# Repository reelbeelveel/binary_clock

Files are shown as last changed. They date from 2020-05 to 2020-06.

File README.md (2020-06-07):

# project objective
The main objective of this project was to create a functioning digital clock using "basic" TTL chips (no Arduino, no RTC, etc.) which displays the current time in Binary using 21 Red/Green Light modules (that's 4 bits for milliseconds, 6 bits for seconds, 6 bits for minutes, 4 bits for the hour, and one bit for AM/PM).
# clock datapath revision 1
My first revision of the clock's main datapath was a BEAST. At this time, I was still pretty committed to building the system using low level components only, so this circuit board was monstrous.



In the second revision, (coming soon) I plan on replacing the adder/and/register structure (pictured below for the millisecond system) with a simple decade counter (7493). In my rough sketches, this has reduced the number of ICs from 26 to ~16 or so.

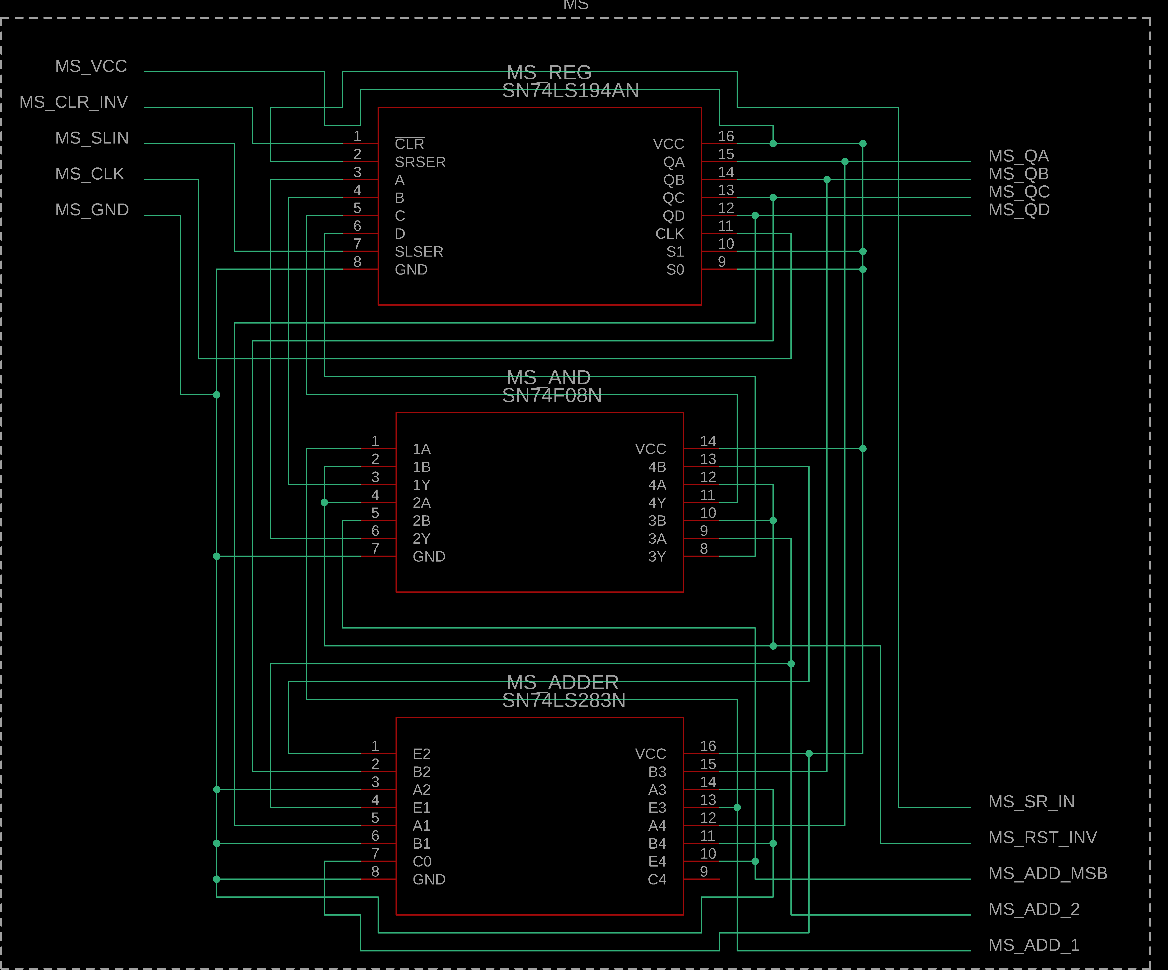
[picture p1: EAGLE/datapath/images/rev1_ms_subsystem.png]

#

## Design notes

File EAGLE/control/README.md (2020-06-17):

# Clock Control

## EAGLE Project, Revision 1*
## Quartus files currently unavailable for this Project.

---

## Schematics

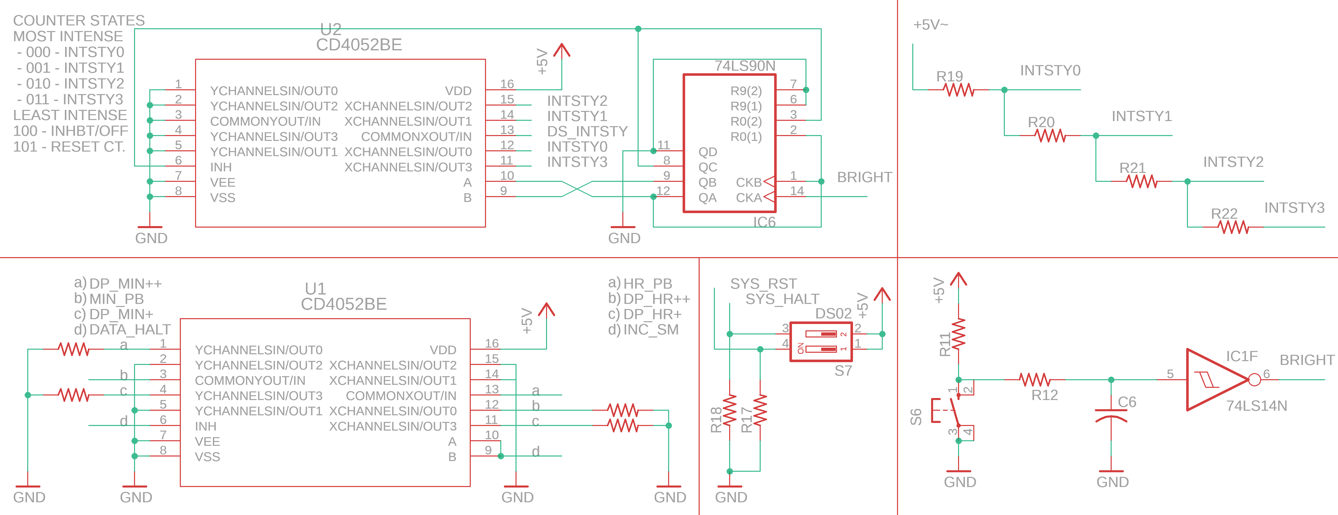
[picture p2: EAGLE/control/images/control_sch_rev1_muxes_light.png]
Control Schematic 1


---

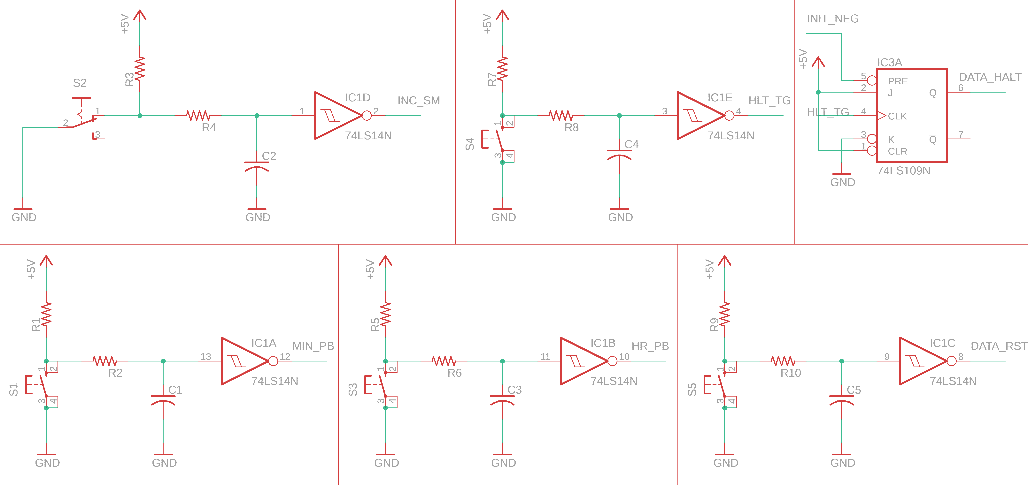
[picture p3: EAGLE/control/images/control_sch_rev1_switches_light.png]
Control Schematic 2


---

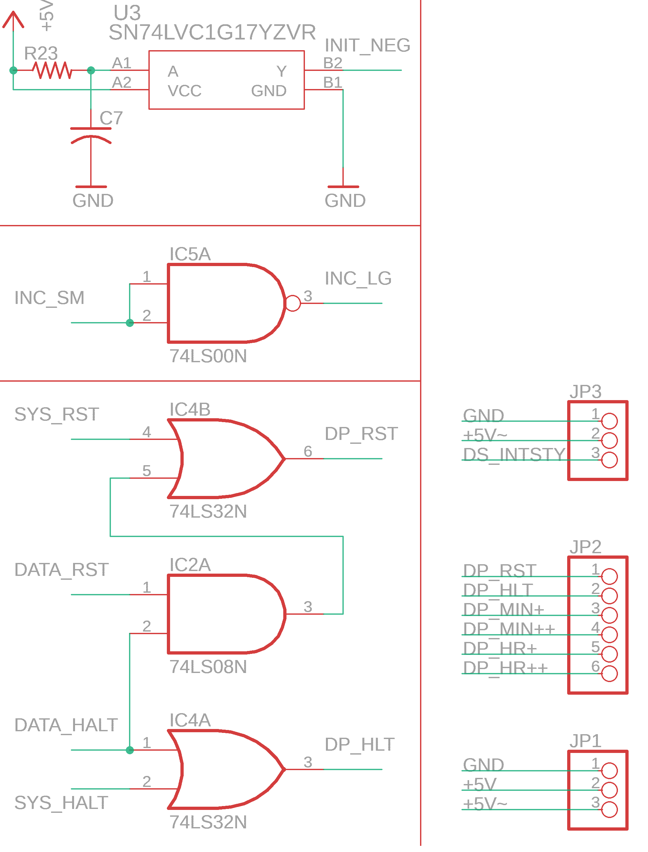
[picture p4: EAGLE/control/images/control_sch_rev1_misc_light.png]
Control Schematic 3


---

## Boards

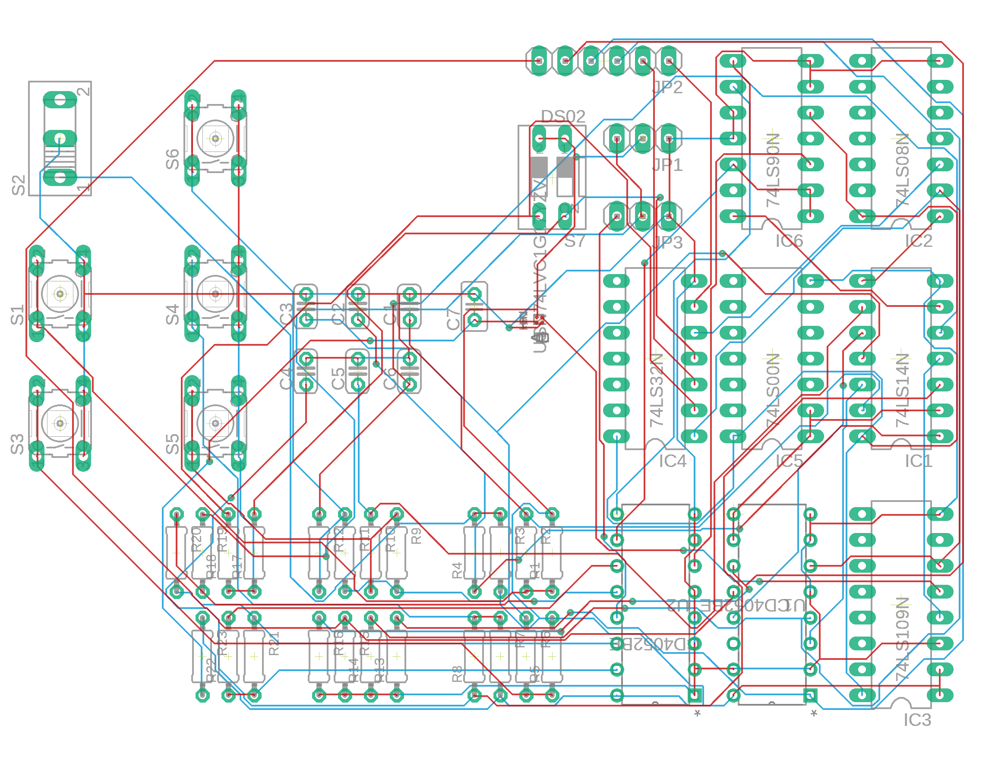
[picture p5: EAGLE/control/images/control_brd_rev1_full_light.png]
Control Board 1


---

## Board Inputs:

| Input Name | Input from Board | Output on Board |
| --- | --- | --- |
| +5V | Power | 5V |
| +5V~ | Power | 5V~ |
| GND | Power | GND |

---

## Board Outputs:

| Output Name | Output to Board | Input on Board |
| --- | --- | --- |
| DP_RST | Datapath | RST |
| DP_HLT | Datapath | HALT |
| DP_MIN+ | Datapath | ADD_MIN |
| DP_MIN++ | Datapath | ADD_MIN_LG |
| DP_HR+ | Datapath | ADD_HR |
| DP_HR++ | Datapath | ADD_HR_LG |
| DS_INTSTY | Display | INTSTY |
| +5V~ | Display | +5V |
| GND | Display | GND |

---

## TODO/Goals:
- [x] Brightness Control?
- [x] Debounce Inputs
- [ ] Add connectors/offload switches to daughterboard

---

## Components:

- To be updated soon

---

README revised 6/16/2020

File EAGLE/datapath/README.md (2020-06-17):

# Clock Datapath

## *EAGLE Project, Revision 2*
## [View Quartus Files](https://github.com/keelbeelveel/binary_clock/tree/master/quartusII/datapath2.1)

---

## Schematics:
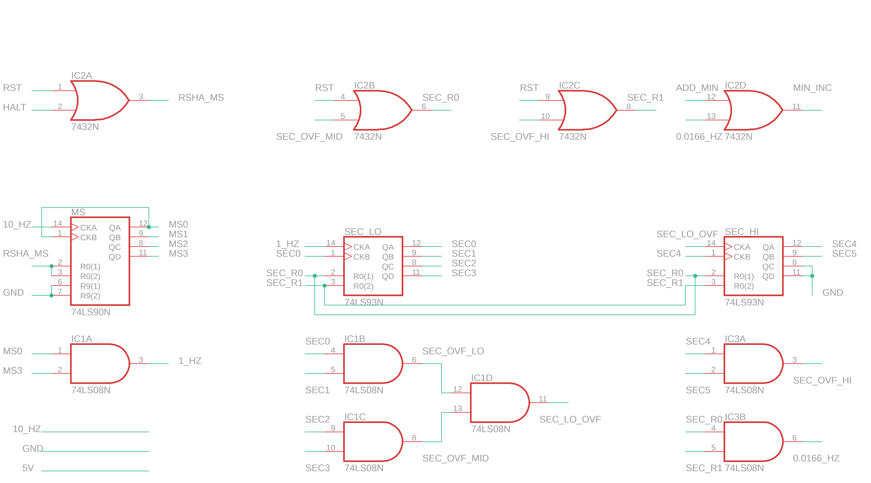
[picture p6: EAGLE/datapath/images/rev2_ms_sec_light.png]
Datapath Schematic 1


---

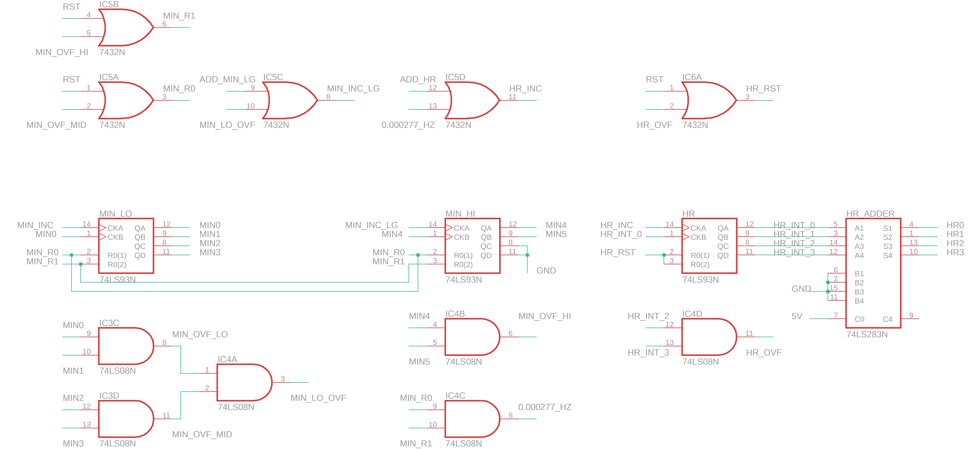
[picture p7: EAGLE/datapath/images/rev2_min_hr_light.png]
Datapath Schematic 2


---

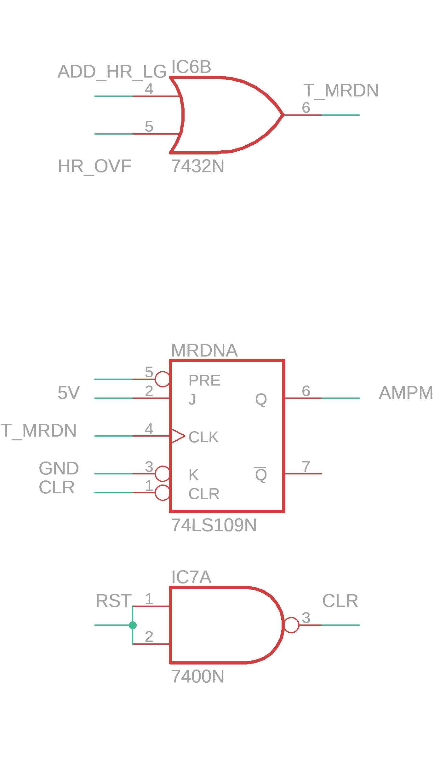
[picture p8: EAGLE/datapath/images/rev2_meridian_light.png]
Datapath Schematic 3


---

## Boards - **WORKING**
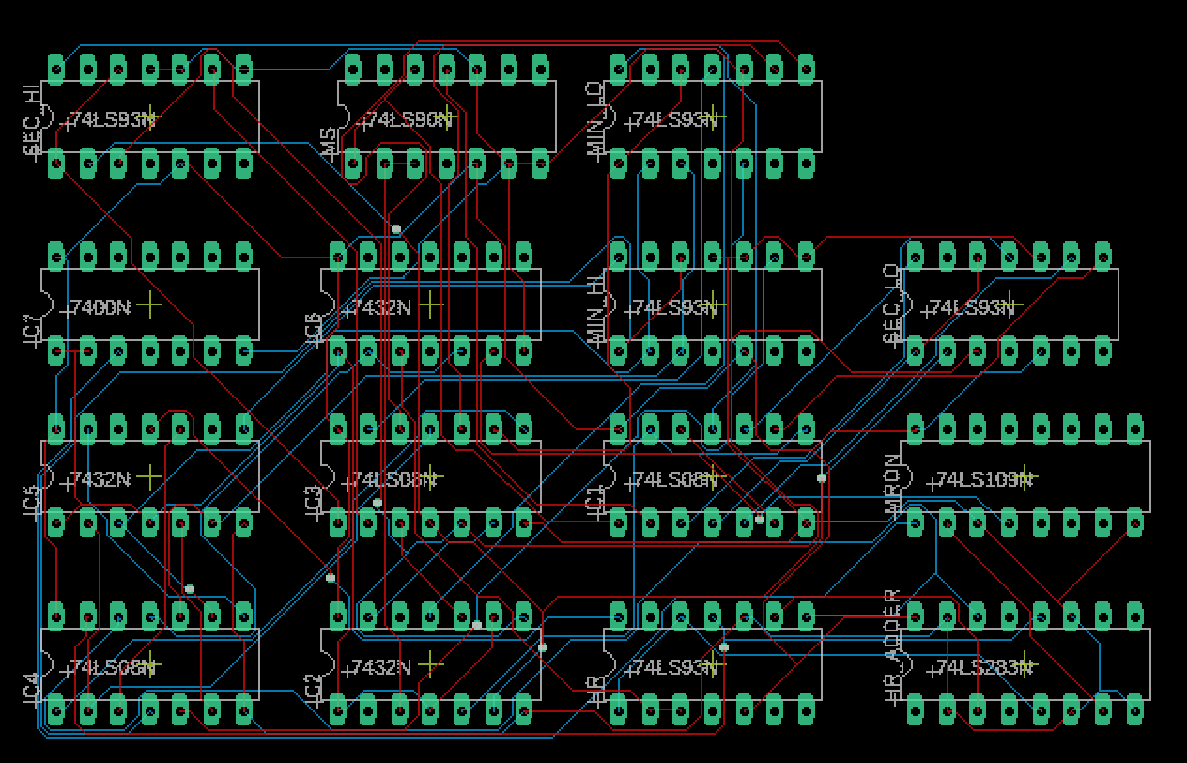
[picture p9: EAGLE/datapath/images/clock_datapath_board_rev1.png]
Board Revision 1


---

## Board Inputs:

| Input Name | Input From Board | Output on Board |
| --- | --- | --- |
| 5V | Power | 5V |
| GND | Power | GND |
| 10_HZ | Power | 10_HZ_OUT |
| RST | Control | DP_RST |
| HALT | Control | DP_HLT |
| ADD_MIN | Control | DP_MIN+ |
| ADD_MIN_LG | Control | DP_MIN++ |
| ADD_HR | Control | DP_HR+ |
| ADD_HR_LG | Control | DP_HR++ |

---

## Board Outputs:

| Output Name | Output to Board | Input on Board |
| --- | --- | --- |
| MS[0:3] | Display | |
| SEC[0:5] | Display | |
| MIN[0:5] | Display | |
| HR[0:3] | Display | |
| AMPM | Display | |

---

## TODO/Goals:

- [ ] Update Board Screenshots to highres/light
---

## Components:
- 1/4x 7400N (NAND)
- 3x 74LS08N (AND)
- 3x 7432N (OR)
- 1x 74LS90N (Decade Counter)
- 5x 74LS93N (Hexadecimal Counter)
- 1/2x 74LS109N (JKFF)
- 1x 74LS283N (Adder)

---

README revised 6/16/2020

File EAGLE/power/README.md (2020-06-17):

# Clock Power

## *EAGLE Project, Revision 1*
## Quartus Files unavailable for this Project.

---

## Schematics 
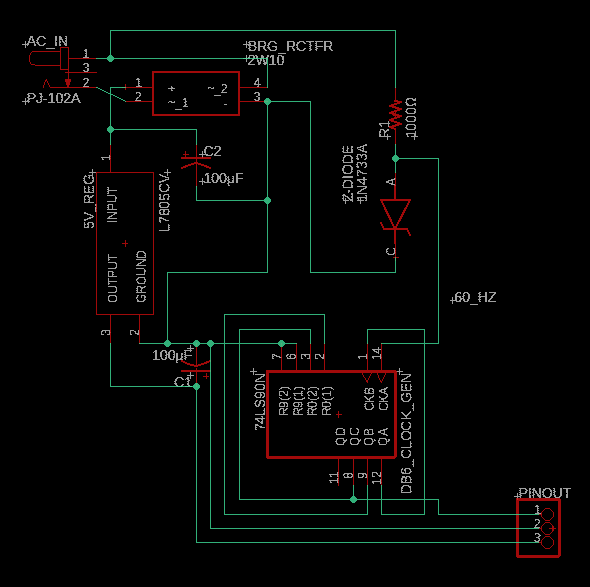
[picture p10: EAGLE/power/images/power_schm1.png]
Power Schematic 1


---

## Boards
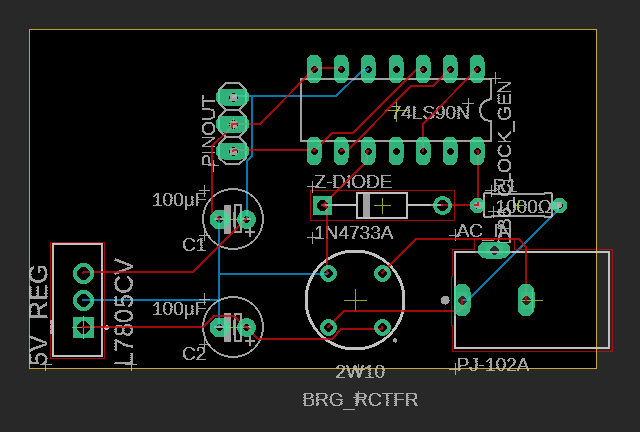
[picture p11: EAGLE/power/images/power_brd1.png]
Image of board v1


---

## Board Inputs:

| Input Name | Input From Board | Output on Board |
| --- | --- | --- |
| AC_IN | N/A | Provided by Barrel Jack |

---

## Board Outputs:

| Output Name | Output to Board | Input on Board |
| --- | --- | --- |
| 5V | Datapath | 5V |
| GND | Datapath | GND |
| 10_HZ_OUT | Datapath | 10_HZ |
| 5V | Display | 5V |
| GND | Display | GND |

---

## TODO/Goals:
- [x] Create stable DC out for main logic circuit/datapath
- [x] Generate 10 Hz Clock signal for main datapath
- [ ] Possibly Separate Power to Display board?

---

## Components:
- Female Barrel Jack (2.1mmx5.5mm) - PJ-102a
- Voltage Regulator: L7805CV - 5VDC Regulator
- Zener Diode: 1N4733a 5.1V Zener Diode, 7mm Pkg
- Rectifier: 2W10 Bridge Rectifier

---

README revised 6/15/2020

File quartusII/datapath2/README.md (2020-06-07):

# Clock Datapath Revision 2 (Quartus)

This directory contains the Quartus II project files used for logic verification of the second version of the Binary Clock datapath. EAGLE/circuit schematics will be soon to follow!

# Findings

Revision 2 functions much better than the first version of the datapath. Using Quartus II, I was able to hardware-verify the logic circuit for the first time using an FPGA (I have the de0-nano, Cyclone IV EP4CE22F17C6N). Unfortunately, I also encountered a few issues which do not appear to be easily solveable. The primary issues seem to be stemming from the 741175 (DFFs) which I had been using to store the upper bits for the seconds and minutes. The main problem is that the 74175 is not well behaved when halted (when no clock is provided), which disrupts and even disables many of the features I want in the clock. The two main flaws I encountered were:

- The add_minute (small) function almost works correctly, but has a fatal flaw.
- The add_minute (large) function does not work at all.

More detailed explanations for these flaws can be found below. Importantly, because designs of the minute subsystem and the second subsystem are nearly identical, it is excedingly likely that these problems are also present in the seconds subsystem (although these flaws are harder to detect because there is no add_seconds() function, the logic would probably fail in the same way).

# Issue : add_minute (small)
When the clock is halted (for editing the time), the small increment add_minute function (which was supposed to add 1 minute to the clock) appears to work correctly, as this can be achieved without the use of the 74175. In fact, this function will work as long as the current time when the function is triggered is not equal to 101111 (47 in base 10).
The cause of this issue is rooted in the fact that incrementing the time from 47 -> 48 (101111 -> 110000) requires both upper bits to flip. Because the circuity surrounding the 74175 is required to perform two operations simultaneously, and because the 74175 is not being ideally clocked (because of the HALT condition required for changing the time) these operations trip each other up and cause unintended behavior.
Instead of properly incrementing from 101111 -> 110000 (47->48), the confused circuitry will incorrectly increment from 101111 -> 010000 (47->2).
Worryingly, it is also possible that this issue could occur during normal operation, and it may even be present within the seconds subsystem, which uses identical circuitry to control its 74175. 
This flaw is seemingly inherent within the 74175, as I cannot think of any easy remedy for this problem without largely restructuring the datapath.

# Issue : add_minute (large)

When the clock is halted (for editing the time), the large increment add_minute function (which was supposed to add 16 minutes to the clock) does not work at all, as there is no way to trigger a read on the 74175 without gating or otherwise tampering with the clock signal.

# Conclusion

As a result of these issues, it would seem at this time that the easiest solution would be to remove the 74175s from the design entirely. In their place, I am considering implementing another 7493 (4 bit counter), as these ICs provide fairly flexible control when it comes to increment/reset which could be handy for the operations I would like to implement. This would be preferable, several extra 7490/7493s on hand.
Alternatively, another solution could be to find a larger counter, like a 6 or 8-bit counter IC and replace the entire subsystem with it.

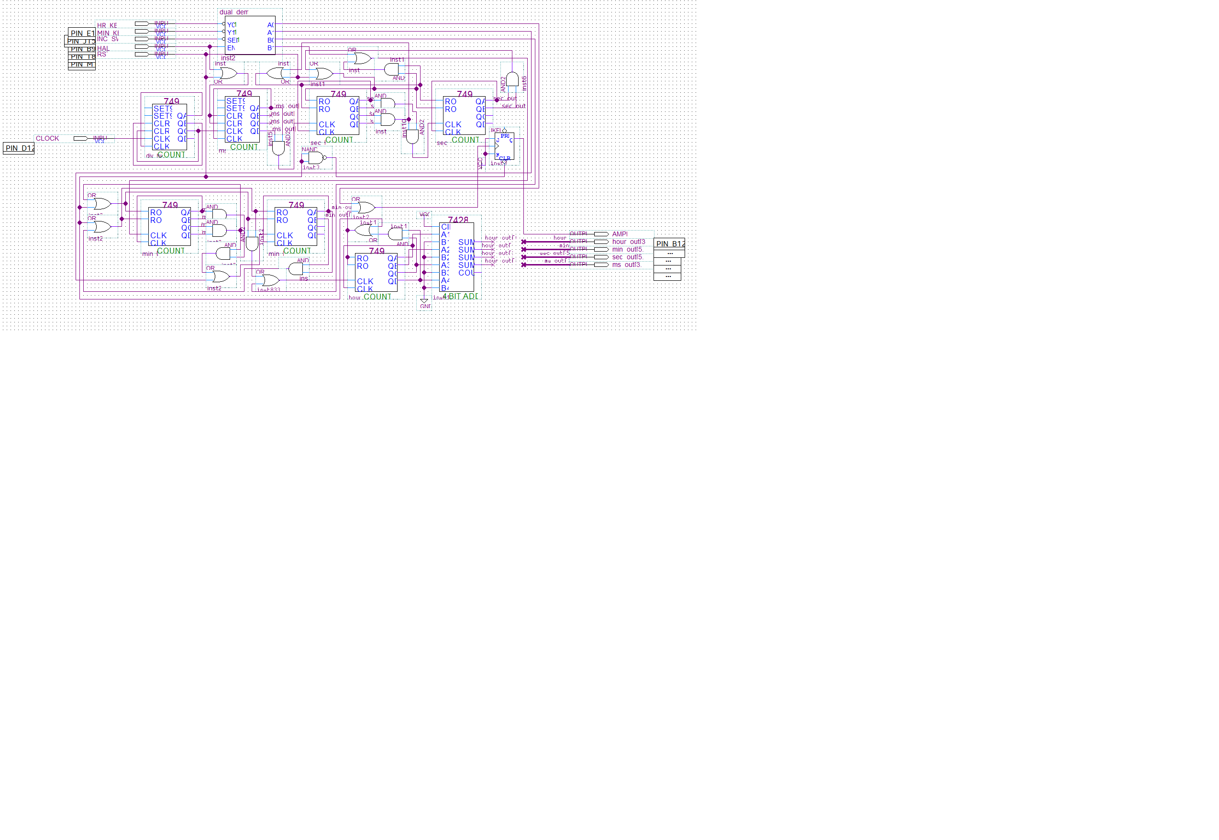
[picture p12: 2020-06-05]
quartusII/Images/clock_d2-1_lv.png

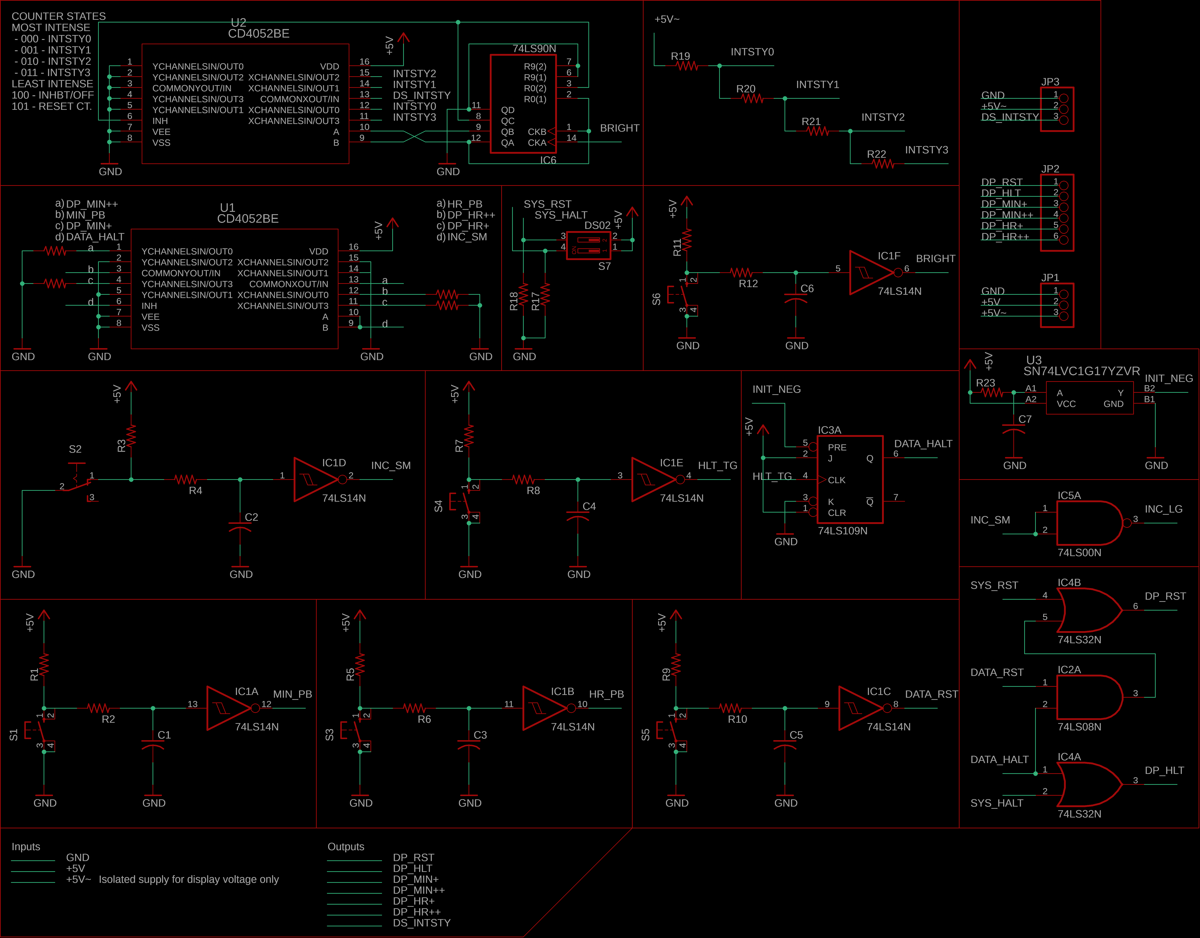
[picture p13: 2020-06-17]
EAGLE/control/images/control_sch_rev1_full.png

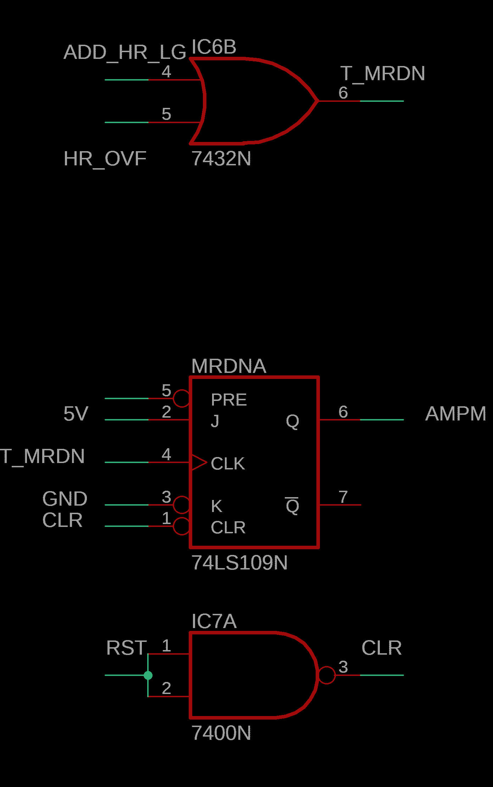
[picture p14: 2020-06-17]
EAGLE/datapath/images/rev2_meridian.png

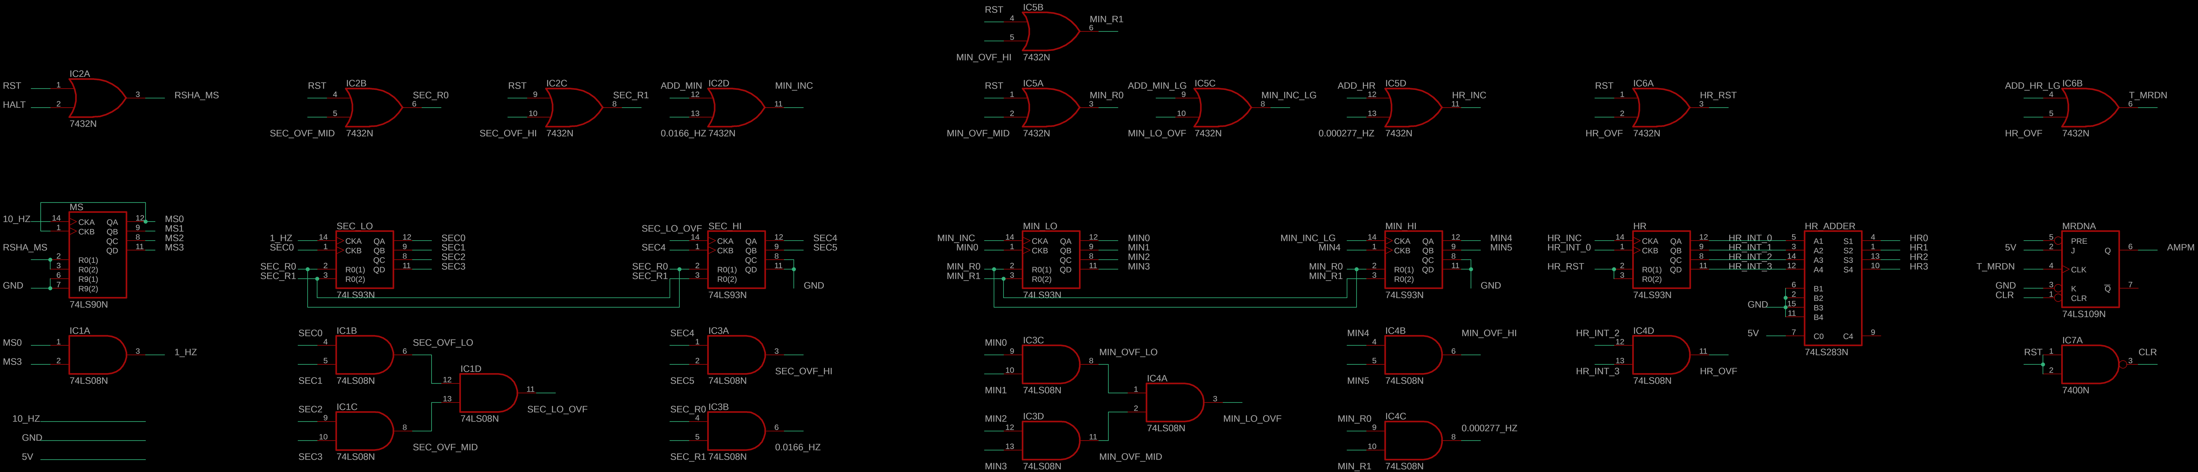
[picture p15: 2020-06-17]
EAGLE/datapath/images/clock_datapath_rev2_full_dark.png

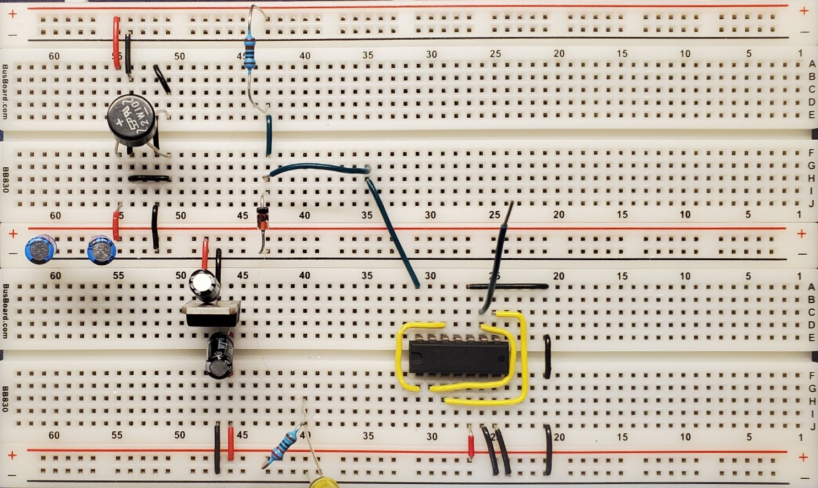
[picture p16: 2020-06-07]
EAGLE/power/images/power_bb.png

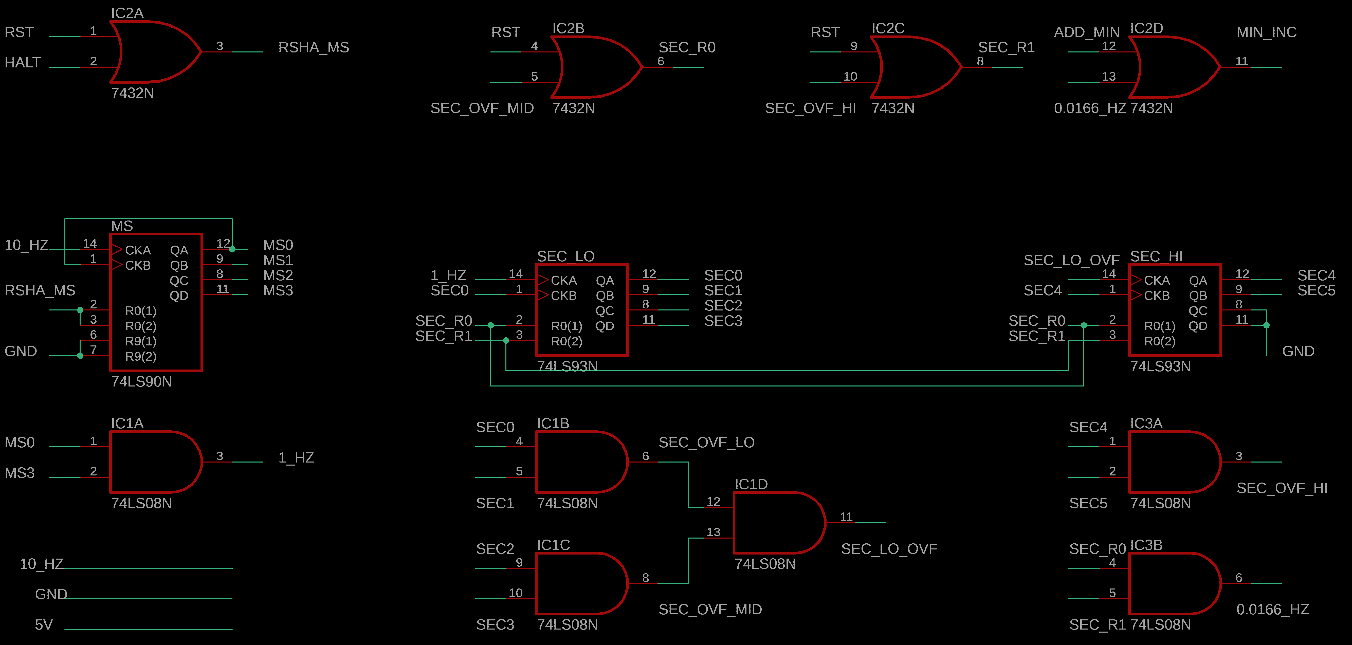
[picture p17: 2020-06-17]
EAGLE/datapath/images/rev2_ms_sec.png

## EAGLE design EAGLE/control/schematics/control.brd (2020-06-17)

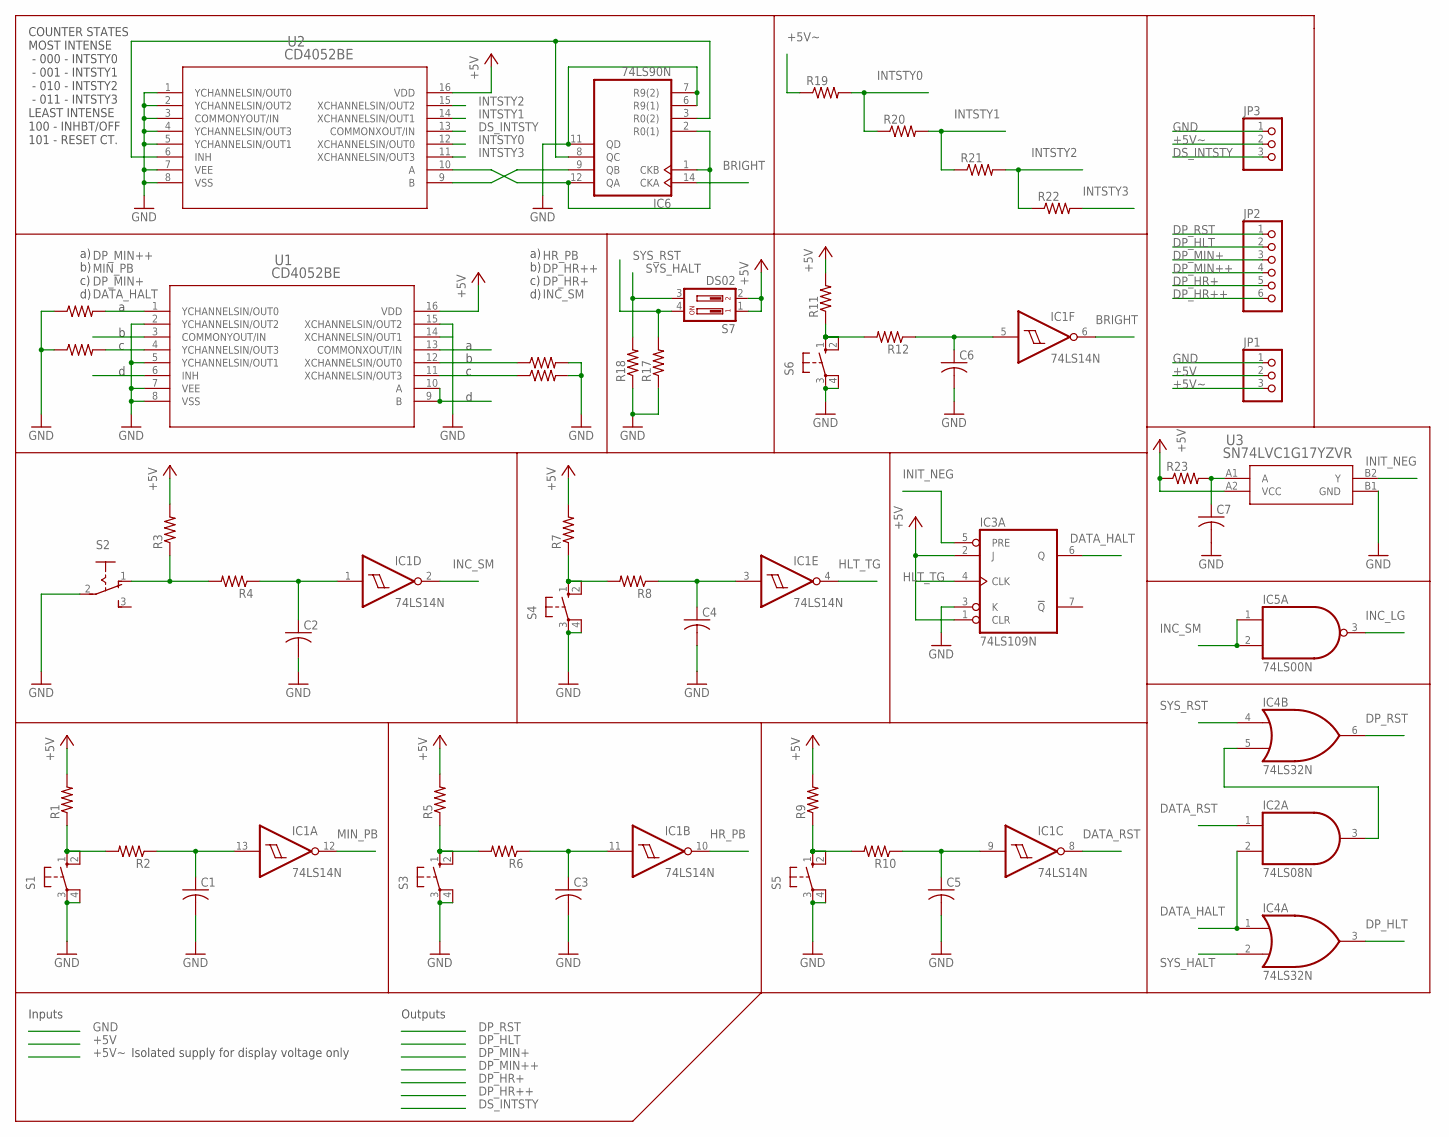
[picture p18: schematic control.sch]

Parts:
C1, C2, C3, C4, C5, C6: C-US025-024X044; C025-024X044
C7: C-US025-025X050; C025-025X050
IC1: 74LS14N; DIL14
IC2: 74LS08N; DIL14
IC3: 74LS109N; DIL16
IC4: 74LS32N; DIL14
IC5: 74LS00N; DIL14
IC6: 74LS90N; DIL14
JP1, JP3: PINHD-1X3; 1X03
JP2: PINHD-1X6; 1X06
R1, R2, R3, R4, R5, R6, R7, R8, R9, R10, R11, R12, R13, R14, R15, R16, R17, R18, R19, R20, R21, R22, R23: R-US_0204/7; 0204/7
S1, S3, S4, S5, S6: 10-XX; B3F-10XX
S2: 255SB
S7: DS02; DS-02
U1, U2: CD4052BE; N16
U3: SN74LVC1G17YZVR; YZV4

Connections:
+5V: IC3.1 (CLR), IC3.2 (J), JP1.2, R1.2, R3.2, R5.2, R7.2, R9.2, R11.2, R23.1, S7.1, S7.2, U1.16 (VDD), U2.16 (VDD), U3.A2 (VCC)
+5V~: JP1.3, JP3.2, R19.1
BRIGHT: IC1.6 (O), IC6.14 (CKA)
DATA_HALT: IC2.2 (I1), IC3.6 (Q), IC4.1 (I0), U1.6 (INH)
DATA_RST: IC1.8 (O), IC2.1 (I0)
DP_HLT: IC4.3 (O), JP2.2
DP_HR+: JP2.5, R16.1, U1.11 (XCHANNELSIN/OUT3)
DP_HR++: JP2.6, R15.1, U1.12 (XCHANNELSIN/OUT0)
DP_MIN+: JP2.3, R14.2, U1.4 (YCHANNELSIN/OUT3)
DP_MIN++: JP2.4, R13.2, U1.1 (YCHANNELSIN/OUT0)
DP_RST: IC4.6 (O), JP2.1
DS_INTSTY: JP3.3, U2.13 (COMMONXOUT/IN)
GND: C1.2, C2.2, C3.2, C4.2, C5.2, C6.2, C7.2, IC1.7 (GND), IC2.7 (GND), IC3.3 (K), IC3.8 (GND), IC4.7 (GND), IC5.7 (GND), IC6.6 (R9(1)), IC6.7 (R9(2)), IC6.10 (GND), IC6.11 (QD), JP1.1, JP3.1, R13.1, R14.1, R15.2, R16.2, R17.1, R18.1, S1.3, S1.4 (P1), S2.2, S3.3, S3.4 (P1), S4.3, S4.4 (P1), S5.3, S5.4 (P1), S6.3, S6.4 (P1), U1.2 (YCHANNELSIN/OUT2), U1.5 (YCHANNELSIN/OUT1), U1.7 (VEE), U1.8 (VSS), U1.15 (XCHANNELSIN/OUT2), U2.1 (YCHANNELSIN/OUT0), U2.2 (YCHANNELSIN/OUT2), U2.3 (COMMONYOUT/IN), U2.4 (YCHANNELSIN/OUT3), U2.5 (YCHANNELSIN/OUT1), U2.7 (VEE), U2.8 (VSS), U3.B1 (GND)
HLT_TG: IC1.4 (O), IC3.4 (CLK)
HR_PB: IC1.10 (O), U1.13 (COMMONXOUT/IN)
INC_LG: IC5.3 (O)
INC_SM: IC1.2 (O), IC5.1 (I0), IC5.2 (I1), U1.9 (B), U1.10 (A)
INIT_NEG: IC3.5 (PRE), U3.B2 (Y)
INTSTY0: R19.2, R20.1, U2.12 (XCHANNELSIN/OUT0)
INTSTY1: R20.2, R21.1, U2.14 (XCHANNELSIN/OUT1)
INTSTY2: R21.2, R22.1, U2.15 (XCHANNELSIN/OUT2)
INTSTY3: R22.2, U2.11 (XCHANNELSIN/OUT3)
MIN_PB: IC1.12 (O), U1.3 (COMMONYOUT/IN)
unnamed: R1.1, R2.2, S1.1 (S), S1.2 (S1)
unnamed: C1.1, IC1.13 (I), R2.1
unnamed: R5.1, R6.2, S3.1 (S), S3.2 (S1)
unnamed: C3.1, IC1.11 (I), R6.1
unnamed: R3.1, R4.2, S2.1 (O)
unnamed: C2.1, IC1.1 (I), R4.1
unnamed: R11.1, R12.2, S6.1 (S), S6.2 (S1)
unnamed: C6.1, IC1.5 (I), R12.1
unnamed: R9.1, R10.2, S5.1 (S), S5.2 (S1)
unnamed: IC2.3 (O), IC4.5 (I1)
unnamed: C5.1, IC1.9 (I), R10.1
unnamed: R7.1, R8.2, S4.1 (S), S4.2 (S1)
unnamed: C4.1, IC1.3 (I), R8.1
unnamed: IC6.3 (R0(2)), IC6.8 (QC), U2.6 (INH)
unnamed: C7.1, R23.2, U3.A1 (A)
unnamed: IC6.9 (QB), U2.9 (B)
unnamed: IC6.1 (CKB), IC6.2 (R0(1)), IC6.12 (QA), U2.10 (A)
SYS_HALT: IC4.2 (I1), R18.2, S7.3
SYS_RST: IC4.4 (I0), R17.2, S7.4
VCC: IC1.14 (VCC), IC2.14 (VCC), IC3.16 (VCC), IC4.14 (VCC), IC5.14 (VCC), IC6.5 (VCC)

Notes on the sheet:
COUNTER STATES MOST INTENSE - 000 - INTSTY0 - 001 - INTSTY1 - 010 - INTSTY2 - 011 - INTSTY3 LEAST INTENSE 100 - INHBT/OFF 101 - RESET CT.
Isolated supply for display voltage only
a) b) c) d)
Inputs
Outputs

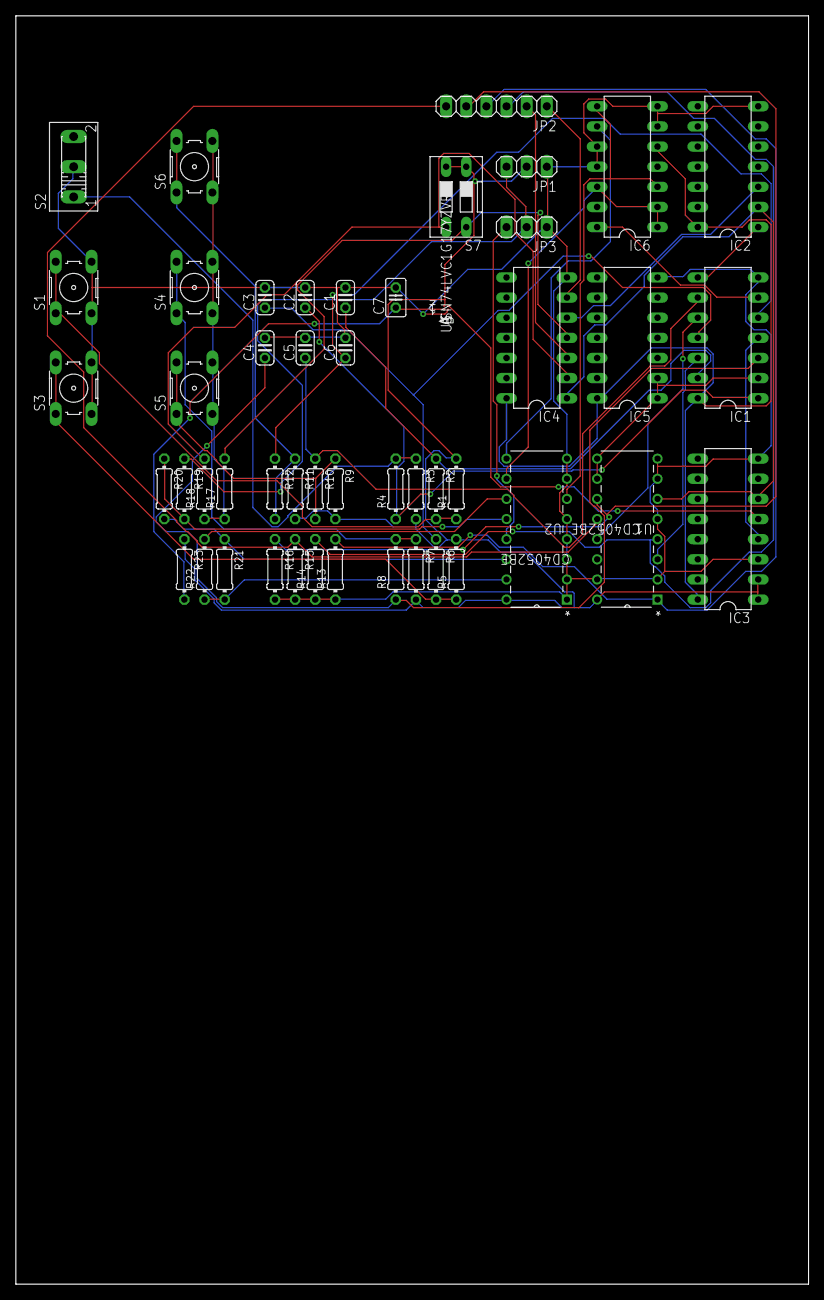
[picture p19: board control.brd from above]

Board: 2 copper layers, 100.0 x 160.0 mm, 49 parts (0 on the bottom side), 42 nets.

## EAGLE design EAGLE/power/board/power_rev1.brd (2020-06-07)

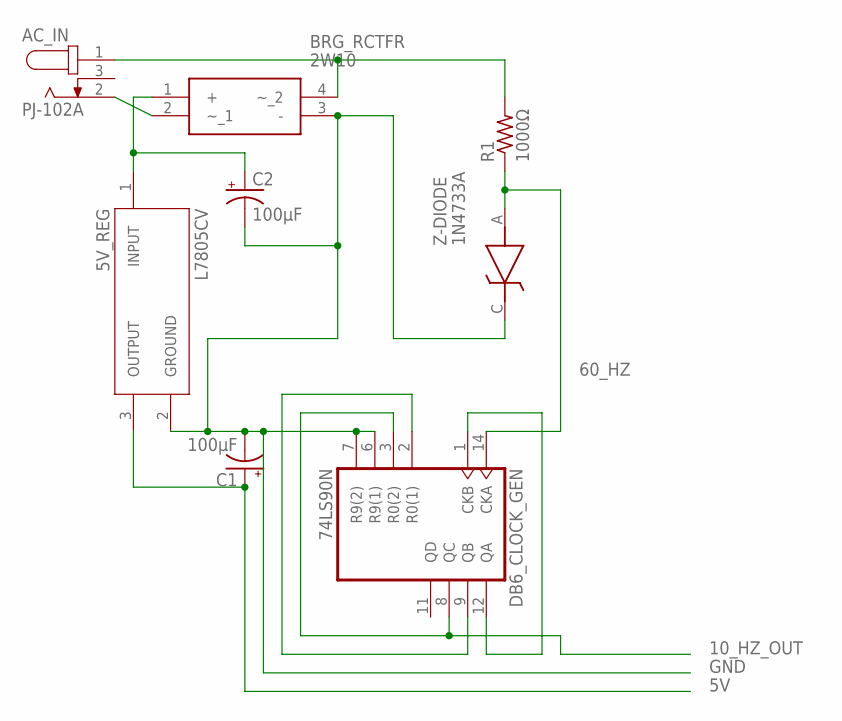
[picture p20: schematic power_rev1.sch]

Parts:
5V_REG: L7805CV; TO255P1040X460X1968-3
AC_IN: PJ-102A; CUI_PJ-102A
BRG_RCTFR: 2W10
C1, C2: 100μF; E2,5-6
DB6_CLOCK_GEN: 74LS90N; DIL14
R1: 1000Ω; 0207/7
Z-DIODE: 1N4733A; DIOAD1125W80L520D270

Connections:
10_HZ_OUT: DB6_CLOCK_GEN.3 (R0(2)), DB6_CLOCK_GEN.8 (QC); also elsewhere on the board
60_HZ: DB6_CLOCK_GEN.14 (CKA), R1.1, Z-DIODE.A
GND: 5V_REG.2 (GROUND), BRG_RCTFR.3 (-), C1.-, C2.-, DB6_CLOCK_GEN.6 (R9(1)), DB6_CLOCK_GEN.7 (R9(2)), DB6_CLOCK_GEN.10 (GND), Z-DIODE.C (K); also elsewhere on the board
unnamed: AC_IN.2, BRG_RCTFR.2 (~_1)
unnamed: AC_IN.1, BRG_RCTFR.4 (~_2), R1.2
unnamed: DB6_CLOCK_GEN.1 (CKB), DB6_CLOCK_GEN.12 (QA)
unnamed: 5V_REG.1 (INPUT), BRG_RCTFR.1 (+), C2.+
unnamed: DB6_CLOCK_GEN.2 (R0(1)), DB6_CLOCK_GEN.9 (QB)
VCC: 5V_REG.3 (OUTPUT), C1.+, DB6_CLOCK_GEN.5 (VCC); also elsewhere on the board

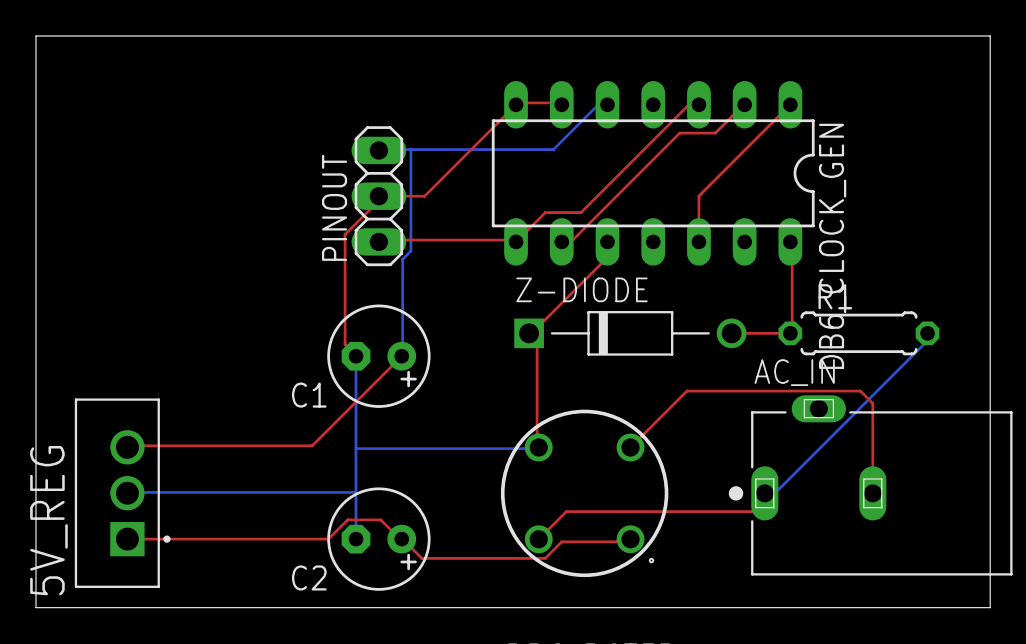
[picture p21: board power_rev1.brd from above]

Board: 2 copper layers, 53.0 x 31.8 mm, 9 parts (0 on the bottom side), 9 nets.

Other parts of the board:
PINOUT: 1X03

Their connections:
10_HZ_OUT: PINOUT.1; also elsewhere on the board
GND: PINOUT.2; also elsewhere on the board
VCC: PINOUT.3; also elsewhere on the board

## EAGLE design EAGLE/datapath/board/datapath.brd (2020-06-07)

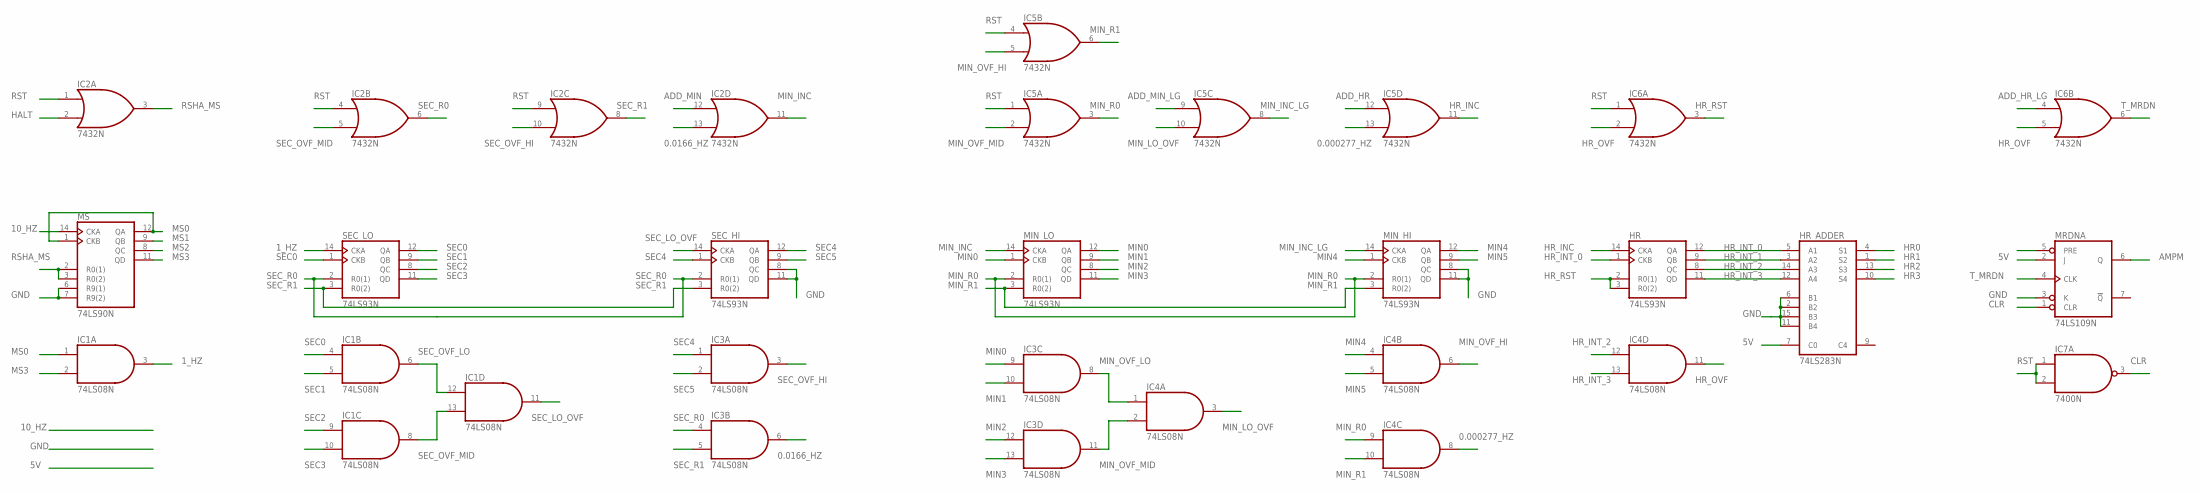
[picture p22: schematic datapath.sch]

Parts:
HR: 74LS93N; DIL14
HR_ADDER: 74LS283N; DIL16
IC1, IC3, IC4: 74LS08N; DIL14
IC2, IC5, IC6: 7432N; DIL14
IC7: 7400N; DIL14
MIN_HI: 74LS93N; DIL14
MIN_LO: 74LS93N; DIL14
MRDN: 74LS109N; DIL16
MS: 74LS90N; DIL14
SEC_HI: 74LS93N; DIL14
SEC_LO: 74LS93N; DIL14

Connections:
0.0166_HZ: IC2.13 (I1), IC3.6 (O)
0.000277_HZ: IC4.8 (O), IC5.13 (I1)
1_HZ: IC1.3 (O), SEC_LO.14 (CKA)
5V: HR_ADDER.7 (C0), MRDN.2 (J)
10_HZ: MS.14 (CKA)
ADD_HR: IC5.12 (I0)
ADD_HR_LG: IC6.4 (I0)
ADD_MIN: IC2.12 (I0)
ADD_MIN_LG: IC5.9 (I0)
AMPM: MRDN.6 (Q)
CLR: IC7.3 (O), MRDN.1 (CLR)
GND: HR.10 (GND), HR_ADDER.2 (B2), HR_ADDER.6 (B1), HR_ADDER.8 (GND), HR_ADDER.11 (B4), HR_ADDER.15 (B3), IC1.7 (GND), IC2.7 (GND), IC3.7 (GND), IC4.7 (GND), IC5.7 (GND), IC6.7 (GND), IC7.7 (GND), MIN_HI.8 (QC), MIN_HI.10 (GND), MIN_HI.11 (QD), MIN_LO.10 (GND), MRDN.3 (K), MRDN.8 (GND), MS.6 (R9(1)), MS.7 (R9(2)), MS.10 (GND), SEC_HI.8 (QC), SEC_HI.10 (GND), SEC_HI.11 (QD), SEC_LO.10 (GND)
HALT: IC2.2 (I1)
HR0: HR_ADDER.4 (S1)
HR1: HR_ADDER.1 (S2)
HR2: HR_ADDER.13 (S3)
HR3: HR_ADDER.10 (S4)
HR_INC: HR.14 (CKA), IC5.11 (O)
HR_INT_0: HR.1 (CKB), HR.12 (QA), HR_ADDER.5 (A1)
HR_INT_1: HR.9 (QB), HR_ADDER.3 (A2)
HR_INT_2: HR.8 (QC), HR_ADDER.14 (A3), IC4.12 (I0)
HR_INT_3: HR.11 (QD), HR_ADDER.12 (A4), IC4.13 (I1)
HR_OVF: IC4.11 (O), IC6.2 (I1), IC6.5 (I1)
HR_RST: HR.2 (R0(1)), HR.3 (R0(2)), IC6.3 (O)
MIN0: IC3.9 (I0), MIN_LO.1 (CKB), MIN_LO.12 (QA)
MIN1: IC3.10 (I1), MIN_LO.9 (QB)
MIN2: IC3.12 (I0), MIN_LO.8 (QC)
MIN3: IC3.13 (I1), MIN_LO.11 (QD)
MIN4: IC4.4 (I0), MIN_HI.1 (CKB), MIN_HI.12 (QA)
MIN5: IC4.5 (I1), MIN_HI.9 (QB)
MIN_INC: IC2.11 (O), MIN_LO.14 (CKA)
MIN_INC_LG: IC5.8 (O), MIN_HI.14 (CKA)
MIN_LO_OVF: IC4.3 (O), IC5.10 (I1)
MIN_OVF_HI: IC4.6 (O), IC5.5 (I1)
MIN_OVF_LO: IC3.8 (O), IC4.1 (I0)
MIN_OVF_MID: IC3.11 (O), IC4.2 (I1), IC5.2 (I1)
MIN_R0: IC4.9 (I0), IC5.3 (O), MIN_HI.2 (R0(1)), MIN_LO.2 (R0(1))
MIN_R1: IC4.10 (I1), IC5.6 (O), MIN_HI.3 (R0(2)), MIN_LO.3 (R0(2))
MS0: IC1.1 (I0), MS.1 (CKB), MS.12 (QA)
MS1: MS.9 (QB)
MS2: MS.8 (QC)
MS3: IC1.2 (I1), MS.11 (QD)
RSHA_MS: IC2.3 (O), MS.2 (R0(1)), MS.3 (R0(2))
RST: IC2.1 (I0), IC2.4 (I0), IC2.9 (I0), IC5.1 (I0), IC5.4 (I0), IC6.1 (I0), IC7.1 (I0), IC7.2 (I1)
SEC0: IC1.4 (I0), SEC_LO.1 (CKB), SEC_LO.12 (QA)
SEC1: IC1.5 (I1), SEC_LO.9 (QB)
SEC2: IC1.9 (I0), SEC_LO.8 (QC)
SEC3: IC1.10 (I1), SEC_LO.11 (QD)
SEC4: IC3.1 (I0), SEC_HI.1 (CKB), SEC_HI.12 (QA)
SEC5: IC3.2 (I1), SEC_HI.9 (QB)
SEC_LO_OVF: IC1.11 (O), SEC_HI.14 (CKA)
SEC_OVF_HI: IC2.10 (I1), IC3.3 (O)
SEC_OVF_LO: IC1.6 (O), IC1.12 (I0)
SEC_OVF_MID: IC1.8 (O), IC1.13 (I1), IC2.5 (I1)
SEC_R0: IC2.6 (O), IC3.4 (I0), SEC_HI.2 (R0(1)), SEC_LO.2 (R0(1))
SEC_R1: IC2.8 (O), IC3.5 (I1), SEC_HI.3 (R0(2)), SEC_LO.3 (R0(2))
T_MRDN: IC6.6 (O), MRDN.4 (CLK)
VCC: HR.5 (VCC), HR_ADDER.16 (VCC), IC1.14 (VCC), IC2.14 (VCC), IC3.14 (VCC), IC4.14 (VCC), IC5.14 (VCC), IC6.14 (VCC), IC7.14 (VCC), MIN_HI.5 (VCC), MIN_LO.5 (VCC), MRDN.16 (VCC), MS.5 (VCC), SEC_HI.5 (VCC), SEC_LO.5 (VCC)

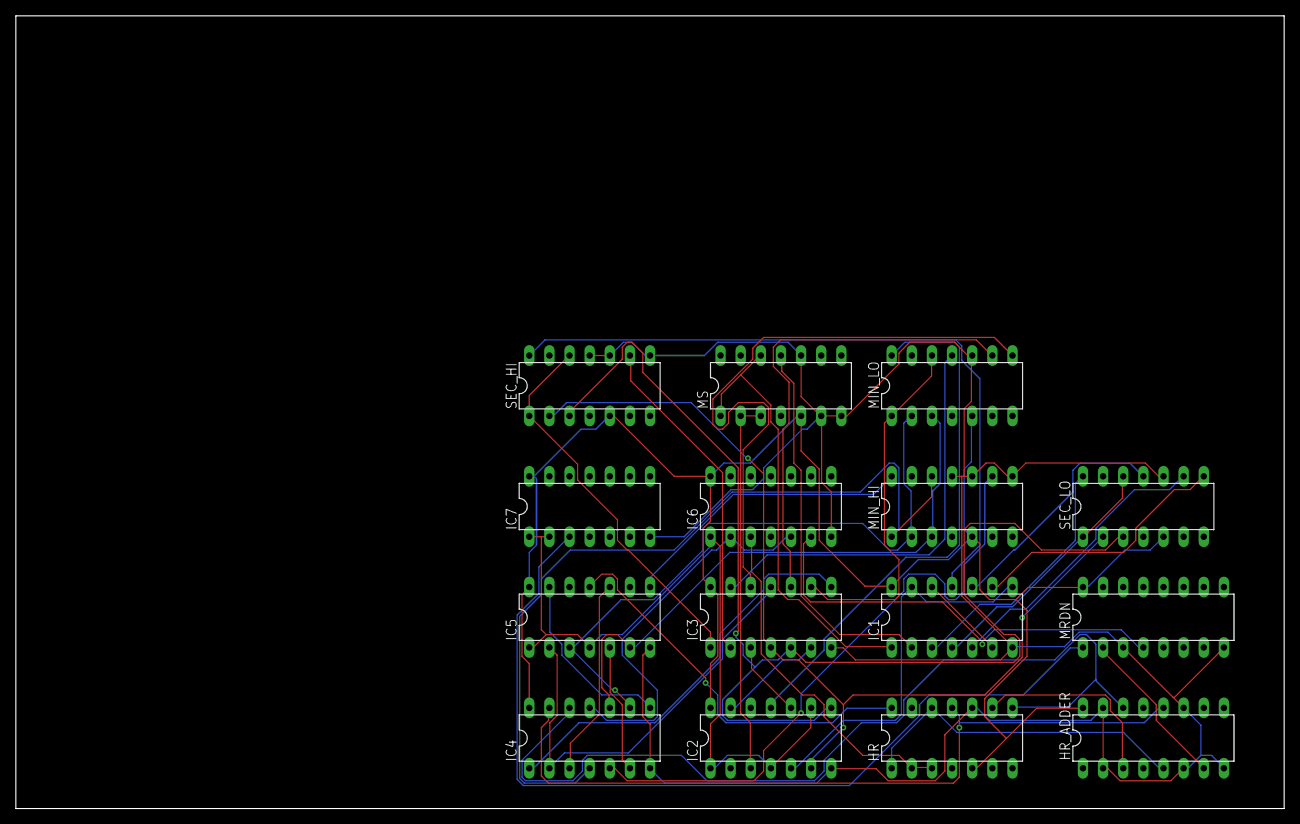
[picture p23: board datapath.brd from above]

Board: 2 copper layers, 160.0 x 100.0 mm, 15 parts (0 on the bottom side), 45 nets.

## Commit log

2020-05-26 Initial Commit.
    [clock.sch, clock_datapath.sch, hi_min_subsystem.sch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]
2020-05-26 reorganized repo structure
    [clock.sch, clock_datapath.sch, hi_min_subsystem.sch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]
2020-06-02 restructured project for q2 files
    [clock.sch, clock_datapath.sch, hi_min_subsystem.sch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]
2020-06-03 v2.1 commit
    [binary_clock_pins.csv, clock.brd]
2020-06-03 2.1 commit - end of night
    [binary_clock_pins.csv, c5_pin_model_dump.txt]
2020-06-07 Finished power board design
    [clock.brd, clock.sch, clock_datapath.sch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]
2020-06-07 Added images for EAGLE/power
2020-06-07 Removed old datapath schematics
    [clock.brd, clock.sch, clock_datapath.sch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]
2020-06-07 Update power_rev1.sch
    Removedf pinout header for conversion to dbl
    [power_rev1.sch]
2020-06-07 added: EAGLE/datapath/schematics/datapath.sch -- completed up to minutes portion
    [datapath.sch]
2020-06-07 completed datapath
    [datapath.sch]
2020-06-07 test board
    [datapath.brd]
2020-06-07 datapath rev2
    [datapath.brd, datapath.sch, power_rev1.brd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]
2020-06-15 straightened net
    [power_rev1.sch]
2020-06-15 added boards, todo, components
2020-06-15 inserted image dividers
2020-06-15 updated board inputs
2020-06-15 updated board outputs
2020-06-15 Moved sch to subdir
    [control.sch]
2020-06-16 end of night commit
    [control.sch]
2020-06-16 Finished CD4052b and DP_RST/HLT
    [control.sch]
2020-06-17 Finished Control Circuit Skeleton
    [control.sch]
2020-06-17 Compiled and autorouted board
    [control.brd]
